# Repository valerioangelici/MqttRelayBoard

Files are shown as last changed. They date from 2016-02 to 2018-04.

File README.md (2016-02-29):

# esp8266MqttRelayBoard
Project for a relay board powered by a esp-12e communicating with a MQTT server

Experimental projects for a esp8266 (esp-12e) driven relay board communicating with the MQTT protocol.
I'm planning to use these with openhab to drive loads with a not high power consumption.
Everything in this project is still experimental so make your valutations before using this material.

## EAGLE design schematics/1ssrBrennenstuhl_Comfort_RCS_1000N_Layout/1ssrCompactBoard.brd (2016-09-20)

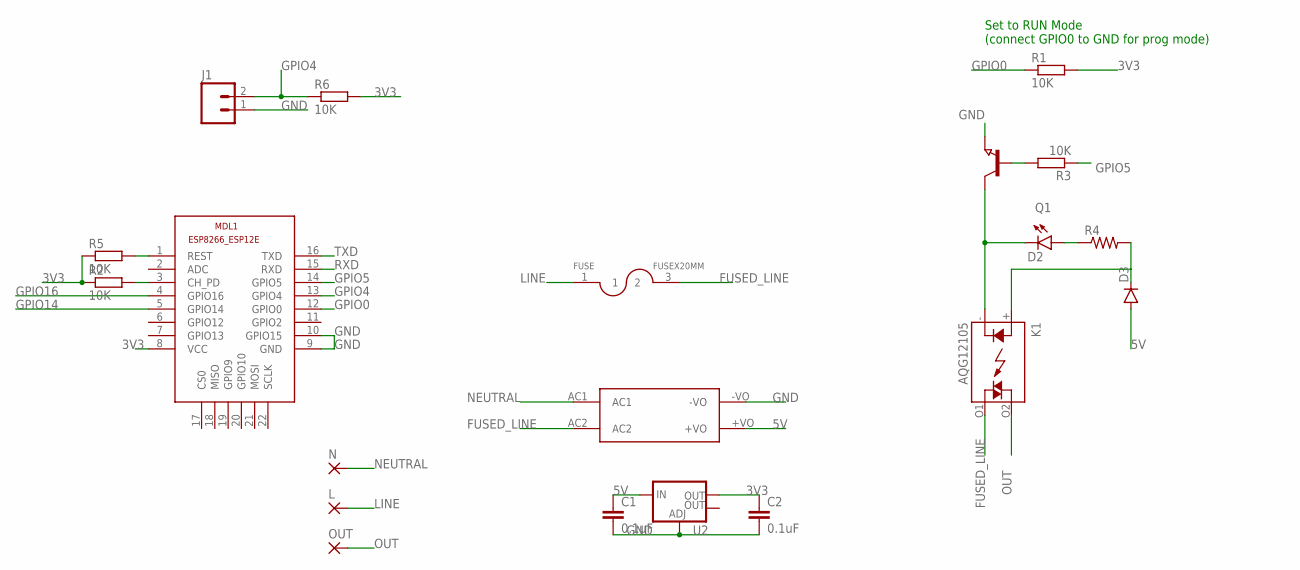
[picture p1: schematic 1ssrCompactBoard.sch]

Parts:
C1, C2: 0.1uF; 0603-CAP
D2: LED0603; LED-0603
D3: DIODESMA; SMA-DIODE
FUSE: FUSEX20MM; FUSE_5MM
J1: M02PTH3; 1X02_LONGPADS
K1: AQG12105; AQG
L: 3,81/1,1
MDL1: ESP8266-12EESP8266-ESP12E; ESP8266-ESP12E
N: 3,81/1,1
OUT: 3,81/1,1
Q1: NPN-TRANSISTOR_SOT23; SOT23
R1, R2, R3, R5, R6: 10K; R0805
R4: RESISTOR0603; 0603-RES
U2: V_REG_LM1117SOT223; SOT223
U$4: HLK-PM01

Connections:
3V3: C2.1, MDL1.8 (VCC), R1.2, R2.1, R5.1, R6.2, U2.2 (OUT)
5V: C1.1, D3.A, U2.3 (IN), U$4.+VO
FUSED_LINE: FUSE.3 (2), K1.O1 (DS2), U$4.AC2
GND: C1.2, C2.2, J1.1, MDL1.9 (GND), MDL1.10 (GPIO15), Q1.2 (E), U2.1 (ADJ), U$4.-VO
GPIO0: MDL1.12 (GPIO0), R1.1
GPIO4: J1.2, MDL1.13 (GPIO4), R6.1
GPIO5: MDL1.14 (GPIO5), R3.1
GPIO14: MDL1.5 (GPIO14)
GPIO16: MDL1.4 (GPIO16)
LINE: FUSE.1, L.1
unnamed: D2.A, R4.1
unnamed: D3.C, K1.+ (A), R4.2
unnamed: MDL1.1 (REST), R5.2
unnamed: MDL1.3 (CH_PD), R2.2
unnamed: D2.C, K1.- (K), Q1.3 (C)
unnamed: Q1.1 (B), R3.2
NEUTRAL: N.1, U$4.AC1
OUT: K1.O2 (DS1), OUT.1
RXD: MDL1.15 (RXD)
TXD: MDL1.16 (TXD)

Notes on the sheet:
Set to RUN Mode (connect GPIO0 to GND for prog mode)

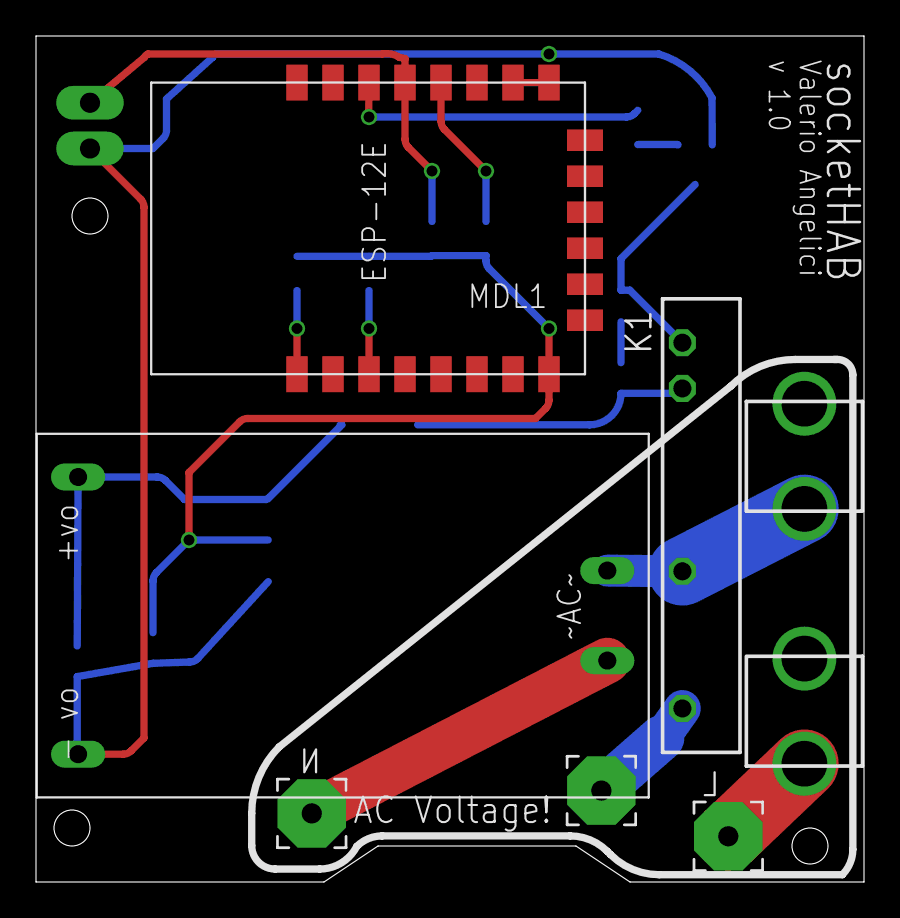
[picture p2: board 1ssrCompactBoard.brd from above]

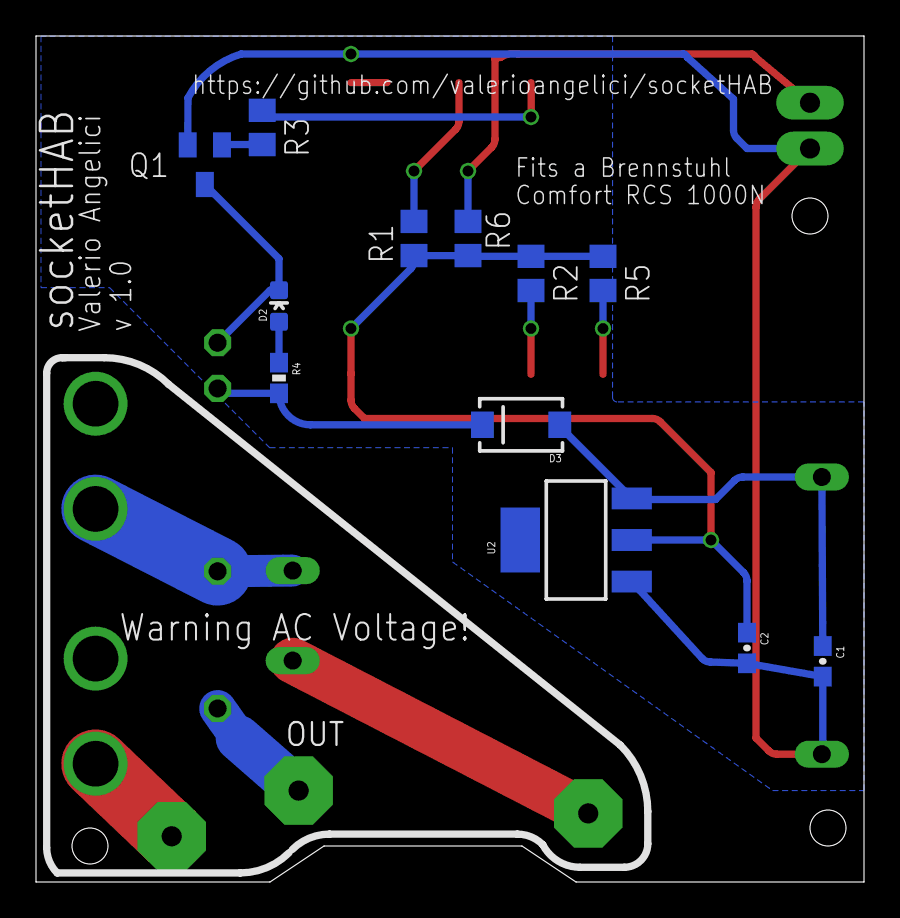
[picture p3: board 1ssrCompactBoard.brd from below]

Board: 2 copper layers, 46.0 x 47.0 mm, 20 parts (12 on the bottom side), 16 nets.

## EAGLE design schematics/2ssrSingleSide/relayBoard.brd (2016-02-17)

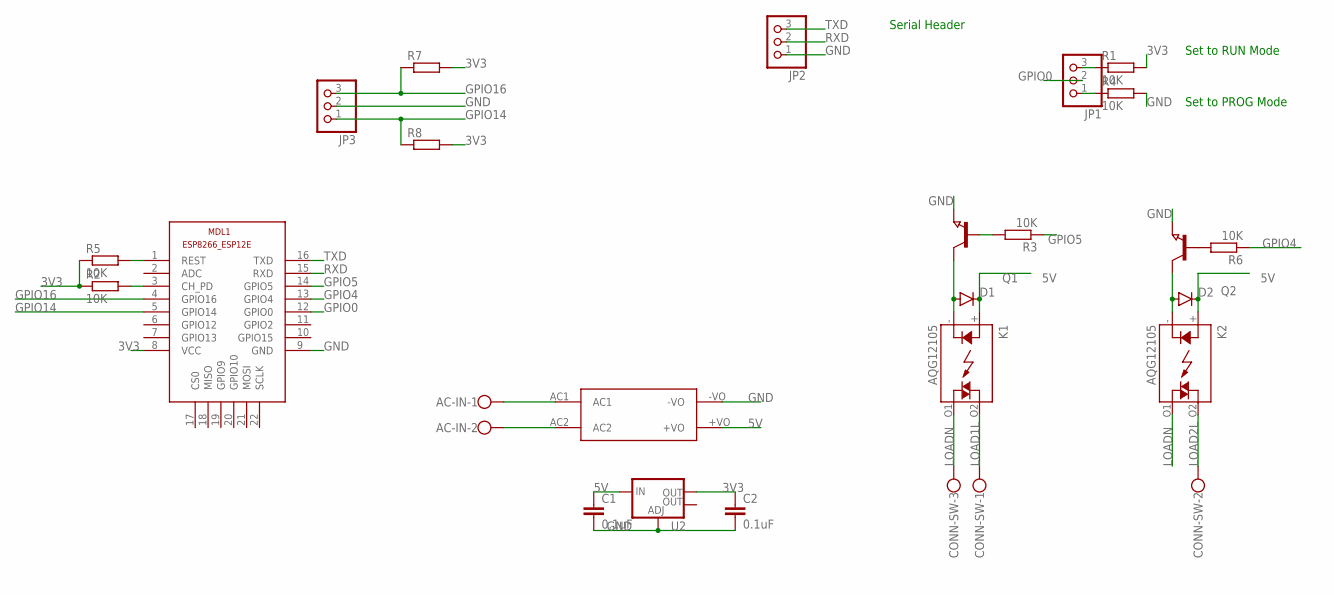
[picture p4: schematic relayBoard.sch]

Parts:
AC-IN: W237-102
C1, C2: 0.1uF; 0603-CAP
CONN-SW: W237-103
D1, D2: DIODESMA; SMA-DIODE
JP1, JP2, JP3: PINHD-1X3; 1X03
K1, K2: AQG12105; AQG
MDL1: ESP8266-12EESP8266-ESP12E; ESP8266-ESP12E
Q1, Q2: NPN-TRANSISTOR_SOT23; SOT23
R1, R2, R3, R4, R5, R6: 10K; R0805
R7, R8: R-EU_R0805; R0805
U2: V_REG_LM1117SOT223; SOT223
U$4: HLK-PM01

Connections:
3V3: C2.1, MDL1.8 (VCC), R1.2, R2.1, R5.1, R7.2, R8.2, U2.2 (OUT)
5V: C1.1, D1.C, D2.C, K1.+ (A), K2.+ (A), U2.3 (IN), U$4.+VO
GND: C1.2, C2.2, JP2.1, JP3.2, MDL1.9 (GND), Q1.2 (E), Q2.2 (E), R4.2, U2.1 (ADJ), U$4.-VO
GPIO0: JP1.2, MDL1.12 (GPIO0)
GPIO4: MDL1.13 (GPIO4), R6.1
GPIO5: MDL1.14 (GPIO5), R3.1
GPIO14: JP3.1, MDL1.5 (GPIO14), R8.1
GPIO16: JP3.3, MDL1.4 (GPIO16), R7.1
LOAD1L: CONN-SW.1, K1.O2 (DS1)
LOAD2L: CONN-SW.2, K2.O2 (DS1)
LOADN: CONN-SW.3, K1.O1 (DS2), K2.O1 (DS2)
unnamed: JP1.3, R1.1
unnamed: AC-IN.1, U$4.AC1
unnamed: JP1.1, R4.1
unnamed: AC-IN.2, U$4.AC2
unnamed: MDL1.1 (REST), R5.2
unnamed: D2.A, K2.- (K), Q2.3 (C)
unnamed: Q2.1 (B), R6.2
unnamed: MDL1.3 (CH_PD), R2.2
unnamed: D1.A, K1.- (K), Q1.3 (C)
unnamed: Q1.1 (B), R3.2
RXD: JP2.2, MDL1.15 (RXD)
TXD: JP2.3, MDL1.16 (TXD)

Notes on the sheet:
Set to RUN Mode
Set to PROG Mode
Serial Header

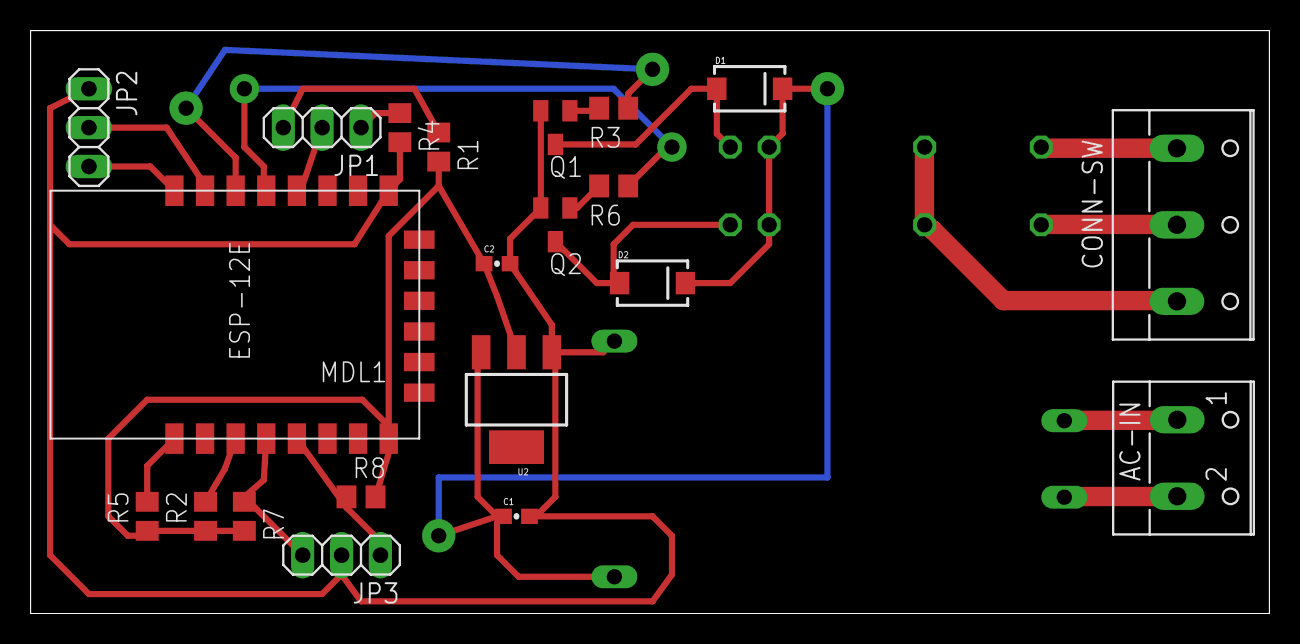
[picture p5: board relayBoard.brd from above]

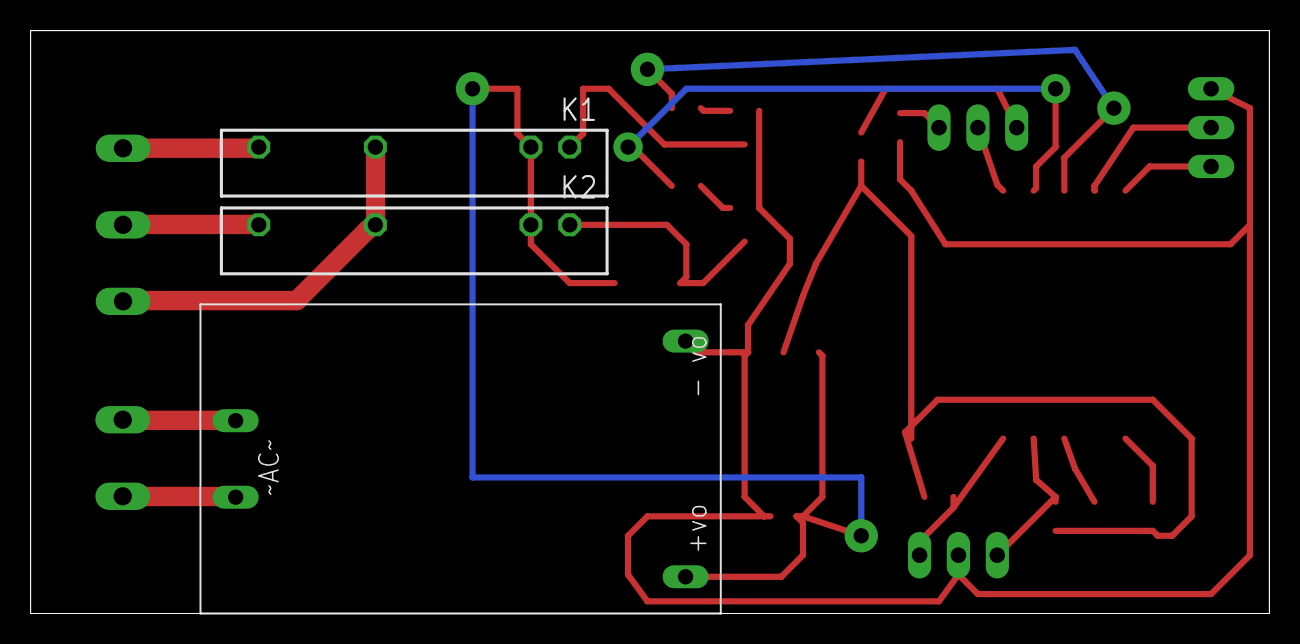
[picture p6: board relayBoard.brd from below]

Board: 2 copper layers, 81.0 x 38.1 mm, 24 parts (3 on the bottom side), 23 nets.

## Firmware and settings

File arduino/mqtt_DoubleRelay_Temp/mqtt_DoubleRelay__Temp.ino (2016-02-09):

/*
  Mqtt ESP8266 relay

  sketch to manage 2 relays via mqtt and physical buttons

  this sketch is built to manage two relays with openhab
  items using the mqtt binding and two physical buttons
  every time a relay is switched on/off the new state is
  sento to a mqtt topic so that openhab is updated even
  when the relay is switched with the physical buttons

*/

#include <ESP8266WiFi.h>
#include <OneWire.h>
#include <PubSubClient.h>
#include <DallasTemperature.h>
//#include <EEPROM.h>
#include "secrets.h"
#include "config.h"
#include "ardprintf.h"


OneWire oneWire(ONE_WIRE_BUS);
DallasTemperature DS18B20(&oneWire);

int lastTempMultiplied = 0;
int relay1Status = 0;
int relay2Status = 0;

//switch related variables
int switch1LastReading = LOW;
int switch2LastReading = LOW;
long lastSwitchTime = 0;
long switchDebounce = 200;

unsigned long lastTickTime = 0;
unsigned long tickCounter = 0;

WiFiClient espClient;
PubSubClient client(espClient);

void setup() {
  pinMode(RELAY_1_PIN, OUTPUT);
  pinMode(RELAY_2_PIN, OUTPUT);
  pinMode(SWITCH_1_PIN, INPUT);
  pinMode(SWITCH_2_PIN, INPUT);
  Serial.begin(115200);

  Serial.println("Hello world!!");

  ardprintf("Tick counter: %d", tickCounter);
  ardprintf("Last temp: %d", lastTempMultiplied);

  setup_wifi();
  client.setServer(mqtt_server, 1883);
  client.setCallback(callback);
  Serial.println("subscribing...");
  client.subscribe(relay_1_command_topic);
  client.loop();
  client.subscribe(relay_2_command_topic);
  Serial.println("Subscribed!!");

}

// Set SDA and SDL ports
// Wire.begin(2, 14);


void setup_wifi() {
  delay(10);
  // We start by connecting to a WiFi network
  unsigned long start = millis();
  Serial.println();
  Serial.print("Connecting to ");
  Serial.println(wifi_ssid);

  WiFi.begin(wifi_ssid, wifi_password);
  WiFi.config(ip, gateway, subnet, dns);

  while (WiFi.status() != WL_CONNECTED) {
    delay(10);
    Serial.print(".");
  }

  Serial.println("");
  Serial.println("WiFi connected");
  Serial.println("IP address: ");
  Serial.println(WiFi.localIP());
  Serial.print("Connected in: ");
  Serial.println(millis() - start);
}

void reconnect() {
  // Loop until we're reconnected
  while (!client.connected()) {
    Serial.print("Attempting MQTT connection...");
    // Attempt to connect
    // If you do not want to use a username and password, change next line to
    // if (client.connect("ESP8266Client")) {
    if (client.connect(mqtt_client_id, mqtt_user, mqtt_password)) {
      Serial.println("connected");
      // Once connected, publish an announcement...
      client.publish("helloTopic", "hello world");
      // ... and resubscribe
      client.subscribe(relay_1_command_topic);
      client.loop();
      client.subscribe(relay_2_command_topic);
    } else {
      Serial.print("failed, rc=");
      Serial.print(client.state());
      Serial.println(" try again in 1 second");
      // Wait 1 second before retrying
      delay(1000);
    }
  }
}

bool checkBound(int newValue, int prevValue, int maxDiff) {
  return newValue < prevValue - maxDiff || newValue > prevValue + maxDiff;
}

void callback(char* topic, byte* payload, unsigned int length) {
  Serial.println("Callback");
  Serial.print("Topic:");
  Serial.println(topic);
  Serial.print("Length:");
  Serial.println(length);
  Serial.print("Payload:");
  Serial.write(payload,length);
  Serial.println();

  if (strcmp(topic,relay_1_command_topic)==0) {
    if (payload[0] == '0'){
      switchRelay(RELAY_1_PIN, LOW);
    } else if(payload[0] == '1') {
      switchRelay(RELAY_1_PIN, HIGH);
    }
  }
  if (strcmp(topic,relay_2_command_topic)==0) {
    if (payload[0] == '0'){
      switchRelay(RELAY_2_PIN, LOW);
    } else if(payload[0] == '1') {
      switchRelay(RELAY_2_PIN, HIGH);
    }
  }

}

void loop() {
  long loopStartMillis = millis();

  //firstly check for millis overflow (every about 50 days)  
  if(lastTickTime > millis()){
    Serial.println("millis overflow, resetting counters");
    //millis overflow , reset the other counters too
    lastTickTime = millis();
    tickCounter = 0;
  }
  //client loop to allow wifi and mqtt packets handling
  client.loop();
  //Check for a switch press
  checkSwitches();

  //check if is passed enough time before last tick to generate a new one
  if(millis() - lastTickTime > tickInterval){
    ardprintf("Tick!! counter: %d", tickCounter);
    //check for client disconnection
    if (!client.connected()) {
      reconnect();
    }
    //handle temp sensor actions
    verifyAndSendTemp();
    //update counters
    tickCounter++;
    lastTickTime = millis();
    ardprintf("Tick Loop completed in millis: %d", millis() - loopStartMillis);
  }
}

void verifyAndSendTemp() {
  //Read Temp
  DS18B20.requestTemperatures();
  float newTemp = DS18B20.getTempCByIndex(0);
  int newTempMultiplied = (int)newTemp * 10;
  //send temp every x ticks or if temp changed
  if ((tickCounter % ticksToForceTempUpdate) == 0 || checkBound(newTempMultiplied, lastTempMultiplied, tempDiffToSendUpdate)) {
    char buffer[10];
    String tempC = dtostrf(newTemp, 4, 1, buffer);//handled in sendTemp()
    ardprintf("publishing new temperature: %d", newTemp);
    client.publish(temperature_topic, String(tempC).c_str(), true);
    lastTempMultiplied = newTempMultiplied;
  }
}

void checkSwitches() {
  //read and process switch 1
  int switch1Reading = digitalRead(SWITCH_1_PIN);
    if(switch1Reading == HIGH && switch1LastReading == LOW && millis() - lastSwitchTime > switchDebounce){
      if(relay1Status == 1){
        switchRelay(RELAY_1_PIN, LOW);
      } else {
        switchRelay(RELAY_1_PIN, HIGH);
      }
      lastSwitchTime = millis();
    }
  switch1LastReading = switch1Reading;

  //read and process switch 2
  int switch2Reading = digitalRead(SWITCH_2_PIN);
    if(switch2Reading == HIGH && switch2LastReading == LOW && millis() - lastSwitchTime > switchDebounce){
      if(relay2Status == 1){
        switchRelay(RELAY_2_PIN, LOW);
      } else {
        switchRelay(RELAY_2_PIN, HIGH);
      }
      lastSwitchTime = millis();
    }
  switch2LastReading = switch2Reading;
}

void switchRelay(int relayPin, int status){
  ardprintf("switchRelay() start relayPin: %d status %d", relayPin, status);
  //check that pin is valid
  if(relayPin == RELAY_1_PIN || relayPin == RELAY_2_PIN){
    //check that status is valid
    if(status == HIGH || status == LOW){
      //if pin and status are valid digital write the new value
      digitalWrite(relayPin, status);
      int statusInt = 0;
      if(status == HIGH){
        statusInt = 1;
      }
      if(relayPin == RELAY_1_PIN){
        client.publish(relay_1_status_topic, String(statusInt).c_str());
        relay1Status = statusInt;
      } else if(relayPin == RELAY_2_PIN) {
        client.publish(relay_2_status_topic, String(statusInt).c_str());
        relay2Status = statusInt;
      }
    }//status pin check
  }//relay pin check
}

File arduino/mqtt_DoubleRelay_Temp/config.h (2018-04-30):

#ifndef CONFIGFILE
#define CONFIGFILE

/*
	MQTT Topics:
	temperature_topic: the topic to send the temperature updates
	relay_1_command_topic: the topic to subscribe to get the relay 1 commands
	rele1_status_topic: the topic where the relay 1 status updates must be published
	rele2_command_topic: the topic to subscribe to get the relay 2 commands
	rele2_status_topic: the topic where the relay 2 status updates must be published
*/
#define temperature_topic "/home/cuci/rb01/temp"
#define relay_1_command_topic "/openHAB/out/CuciRb01Rele1/command"
#define relay_1_status_topic "/openHAB/in/CuciRb01Rele1/state"
#define relay_2_command_topic "/openHAB/out/CuciRb01Rele2/command"
#define relay_2_status_topic "/openHAB/in/CuciRb01Rele2/state"

//led pin is 13
#define RELAY_1_PIN 4
#define RELAY_2_PIN 5
#define SWITCH_1_PIN 12
#define SWITCH_2_PIN 13
#define ONE_WIRE_BUS 2 // DS18B20 on arduino pin2 corresponds to D4 on physical board

int tempDiffToSendUpdate = 1; //this is in tenths of C (1 = 0.1C)
unsigned long tickInterval = 15000; // in millis
unsigned long ticksToForceTempUpdate = 900; // in ticks
unsigned long forceRelayStatusUpdateTicks = 900; // in ticks
unsigned long LONG_PRESS_MILLIS = 2000;

//EEPROM config is not used actually
// #define EEPROM_SWITCH          0
// #define EEPROM_TICK_INTERVAL       4
// #define EEPROM_SEND_INTERVAL_TICKS       8
// #define EEPROM_LAST_TEMP      12
// #define EEPROM_TEMP_DIFF_UPDATE      16
// #define EEPROM_RELAY_1_STATUS      20
// #define EEPROM_RELAY_2_STATUS      24


#endif // #ifndef CONFIGFILE

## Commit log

2016-02-12 board and schematics work in progress
    [relayBoard.brd, relayBoard.sch]
2016-02-15 code and schematic modifications
    [relayBoard.brd, relayBoard.sch]
2016-02-17 moved schematics and board
    [relayBoard.brd, relayBoard.sch]
2016-02-29 Added Brennenstuhl_Comfort_RCS_1000N_Layout work in progress
    [1ssrCompactBoard.brd, 1ssrCompactBoard.sch]
2016-03-02 placed fuse on pcb
    [1ssrCompactBoard.brd, 1ssrCompactBoard.sch]
2016-03-04 board routing work in progress
    [1ssrCompactBoard.brd, 1ssrCompactBoard.sch]
2016-03-09 silkscreen wip
    [1ssrCompactBoard.brd]
2016-03-18 board work in progress
    [1ssrCompactBoard.brd]
2016-09-08 added missing connection on pin gpio15
    [1ssrCompactBoard.brd, 1ssrCompactBoard.sch]
2016-09-08 added ground plane
    [1ssrCompactBoard.brd]
2016-09-08 added setPhyMode and mode to improve wifi stability
    [mqtt_DoubleRelay_Temp.ino]
2016-09-20 diode moved
    [1ssrCompactBoard.brd, 1ssrCompactBoard.sch]
2016-09-20 copied arduino code
2016-09-22 long press switch code
2018-04-27 working on a new Arduino code version

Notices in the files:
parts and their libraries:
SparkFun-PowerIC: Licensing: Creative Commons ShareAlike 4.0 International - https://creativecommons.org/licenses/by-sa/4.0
